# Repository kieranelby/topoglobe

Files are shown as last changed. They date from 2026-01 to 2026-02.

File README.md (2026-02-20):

# 3D Globe Segment Generator

Generate 3D-printable segments that assemble into a globe showing the Earth's ocean depth (Bathymetric) and land height (Topographic, or Raised-Relief).

## Overview

This python program combines elevation data and optional snow coverage data to create 3D models of Earth with raised relief features. The globe is divided into 48 segments that can be 3D printed and assembled. It was developed with the help of Claude Code.

## Appearance

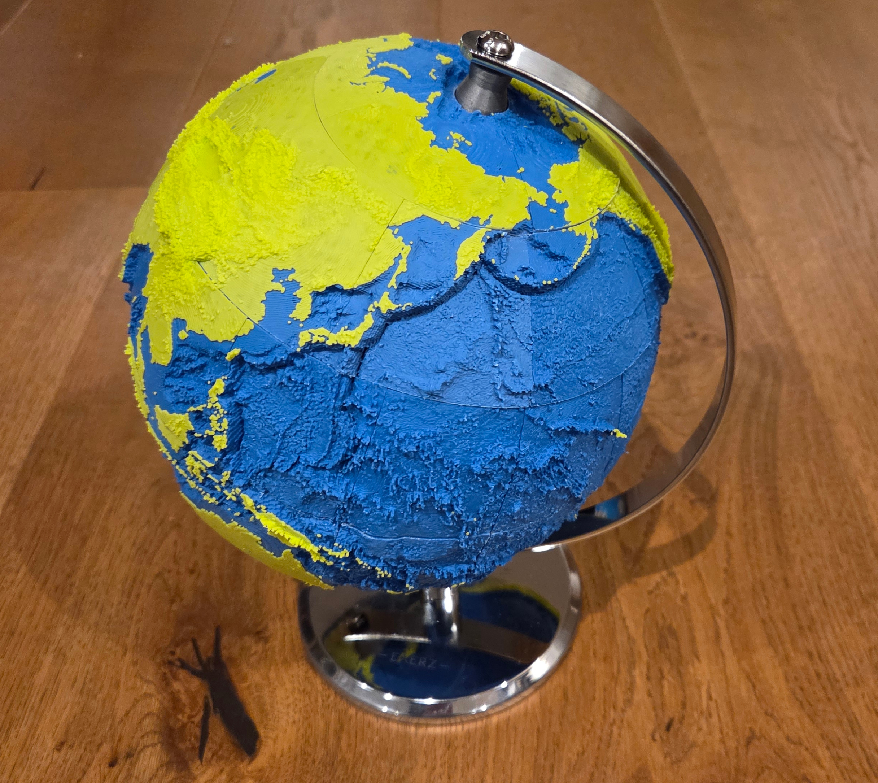
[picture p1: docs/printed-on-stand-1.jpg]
Photo of the printed globe on a stand showing sea off Japan.


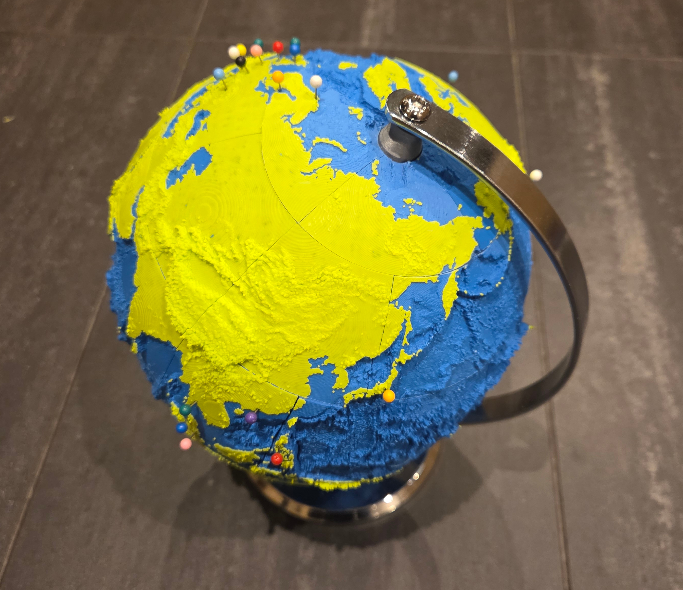
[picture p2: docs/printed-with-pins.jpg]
Photo of the printed globe on a stand with map pins.


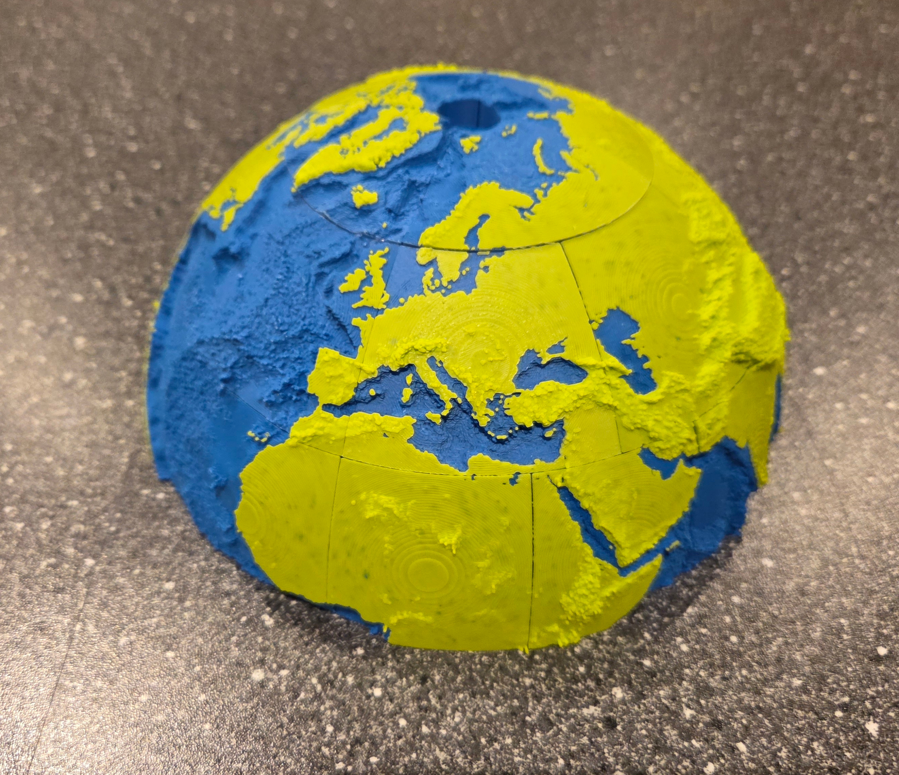
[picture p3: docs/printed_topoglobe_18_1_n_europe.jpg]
Photo of the printed Northern Hemisphere showing Europe.


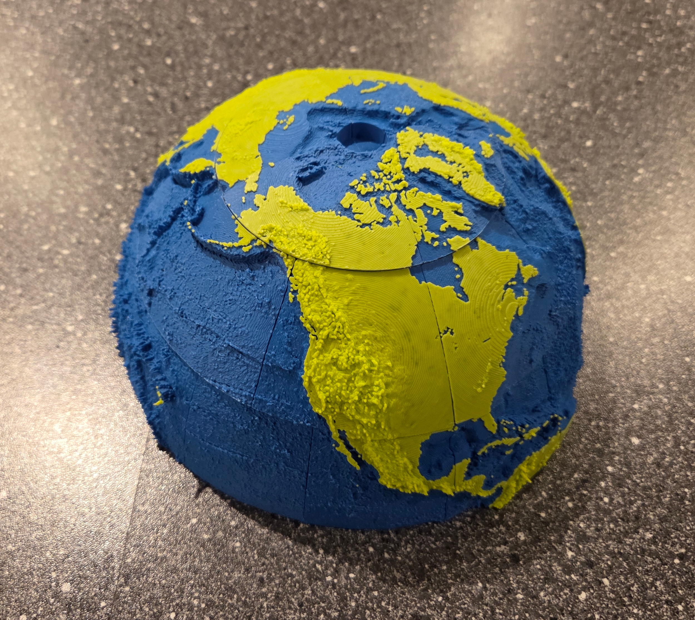
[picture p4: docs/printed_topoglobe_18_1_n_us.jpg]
Photo of the printed Northern Hemisphere showing the US.


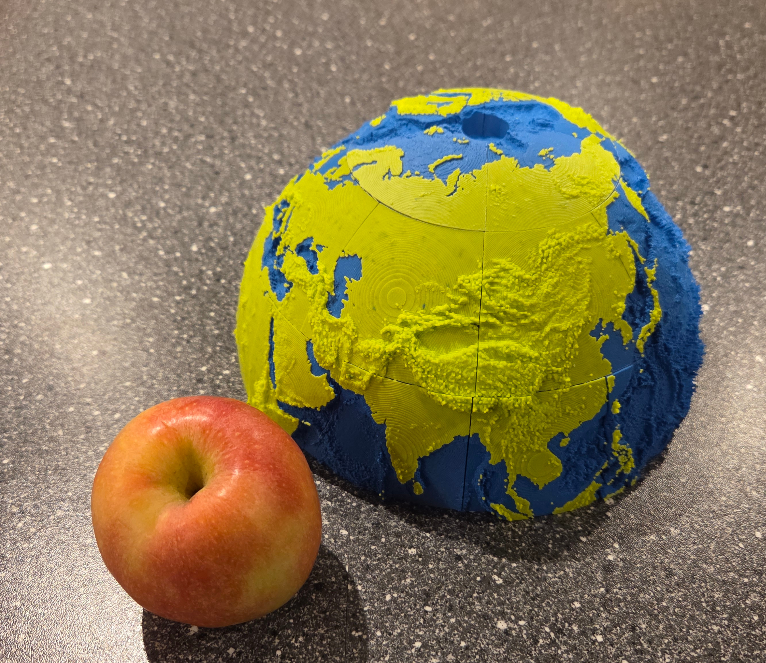
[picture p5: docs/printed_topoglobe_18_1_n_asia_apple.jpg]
Photo of the printed Northern Hemisphere showing Asia with an apple for scale.


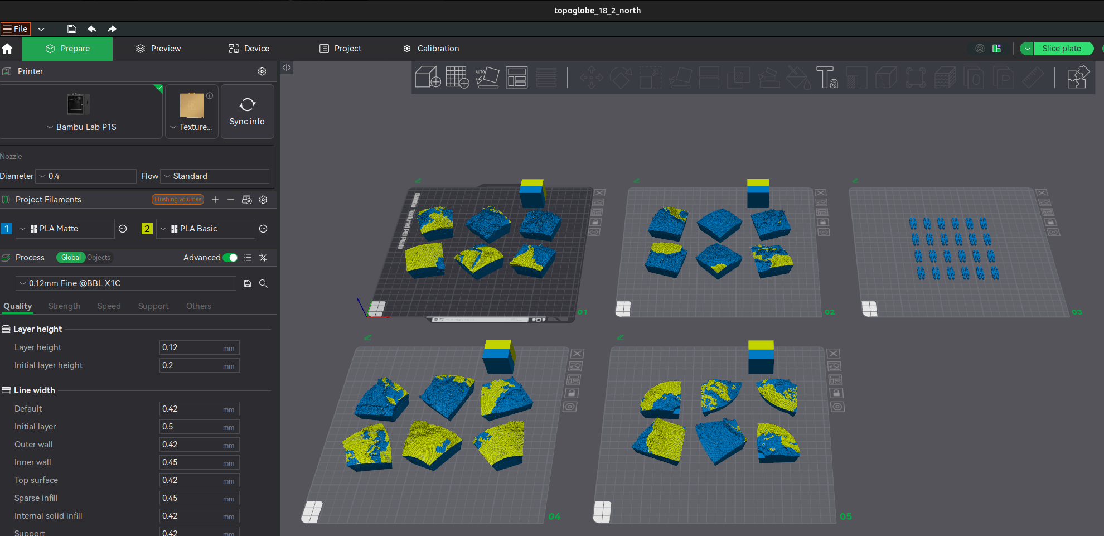
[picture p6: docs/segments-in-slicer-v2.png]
Screenshot of the Northern Hemisphere segments in a slicer.


## Print Ready 3D Files

The 3mf files are too big for github - they can be found on MakerWorld at:

 - [Northern Hemisphere 3mf on MakerWorld](https://makerworld.com/en/models/2254737-topoglobe-topographic-globe-kit-18cm-northern-half#profileId-2455952)
 - [Southern Hemisphere 3mf on MakerWorld](https://makerworld.com/en/models/2264577-topoglobe-topographic-globe-kit-18cm-southern-half#profileId-2467891)

The files are designed for Bambu Studio and have only been printed in a Bambu P1S so far.

## Installation

### Python Dependencies

Install required Python packages:
```bash
pip install -r requirements.txt
```

### Data Files

The geographic data is a bit large and may not be permitted under licensing rules to be included in this repo.

Instead, you will need to download the required data files and place them in the `data/` directory.

There are two data files. You may need to register (for free!) to get access.

#### ETOPO1 1 Arc-Minute Global Relief Model
- Version: ETOPO1 (deprecated!), Bedrock, Grid-Registered
- Download from: https://www.ncei.noaa.gov/products/etopo-global-relief-model
- Format: NetCDF (GMT .grd format)
- Resolution: 60 Arc Seconds
- Post-processing Needed: None
- Target filename: `./data/ETOPO1_Bed_g_gmt4.grd`

#### MODIS Snow Cover (Optional)
- Download from: https://nsidc.org/data/mod10cm
- Spatial Filter: Entire Globe
- Date: I used 1st June 2024 to approximate summer conditions. 
- Download Format: HDF
- Post-processing Needed: Yes
- Use TODO to convert HDF to GeoTIFF in EPSG:4326 projection
- Target filename: `./data/MOD10CM_snow_2024-153.tif`

## Configuration

Edit `config.yaml` if desired:

```yaml
# Data files
etopo_path: "./data/ETOPO1_Bed_g_gmt4.grd"
snow_path: "./data/MOD10CM_snow_2024-153.tif"  # Optional

# Globe parameters
radius_mm: 90.0              # Base radius in millimeters
elevation_range_mm: 15.0     # Height range for elevation features
min_height_mm: 0.2           # Minimum feature height
shell_thickness_mm: 7.0      # Wall thickness of the globe shell

# Grid parameters
step_deg: 0.333333           # Grid cell size in degrees (~37km at the equator)

# Output
output_dir: "./output"       # Directory for 3MF files
```

## Usage

### Generate All 48 Segments

```bash
python3 globe.py
```

This will generate all globe segments (without snow) and save them as 3MF files in the output directory. Takes approximately **9-10 minutes** for all 48 segments at 0.333333° resolution.

### Generate Specific Segments

```bash
python3 globe.py -s N60-90_E000-090 N60-90_E090-180
```

### Enable Snow Layer

```bash
python3 globe.py --snow
```

Snow is disabled by default for faster processing. Use `--snow` to include snow coverage data.

### Command Line Options

```
usage: globe.py [-h] [--config CONFIG] [--segments SEGMENTS [SEGMENTS ...]]
                [--output-dir OUTPUT_DIR] [--snow] [--verbose]

Generate 3D-printable globe segments from elevation data

optional arguments:
  -h, --help            show this help message and exit
  --config CONFIG, -c CONFIG
                        Path to configuration file (default: config.yaml)
  --segments SEGMENTS [SEGMENTS ...], -s SEGMENTS [SEGMENTS ...]
                        Generate specific segments (e.g., N60-90_E000-090)
  --output-dir OUTPUT_DIR, -o OUTPUT_DIR
                        Override output directory from config
  --snow                Enable snow layer (default: disabled)
  --verbose, -v         Enable verbose logging
```

## Segment Pattern

The globe is divided into 48 segments with increasing density towards the poles:

**Northern Hemisphere:**
- 4 segments: 60°-90° N (90° longitude each)
- 8 segments: 30°-60° N (45° longitude each)
- 12 segments: 0°-30° N (30° longitude each)

**Southern Hemisphere:**
- 12 segments: 0°-30° S (30° longitude each)
- 8 segments: 30°-60° S (45° longitude each)
- 4 segments: 60°-90° S (90° longitude each)

Segment naming: `{N|S}{lat_min}-{lat_max}_{E|W}{lon_min}-{lon_max}`

Examples:
- `N60-90_W180-090` - North Pole segment, 90-180° West
- `N60-90_E000-090` - North Pole segment, 0-90° East
- `S30-60_W090-045` - Southern mid-latitude, 45-90° West

## Output

Each segment is exported as a 3MF file containing **separate objects** for multi-color printing:

- **Water layer** - Ocean depths with hollow core (print in blue)
- **Land layer** - Terrain elevation (print in green/brown)
- **Snow layer** - Snow-covered areas (print in white, only if `--snow` enabled)

### Multi-Color Printing

The 3MF files contain each layer as a separate object, allowing you to assign different colors in your slicer:

1. Load the 3MF file in your slicer (PrusaSlicer, Cura, Bambu Studio, etc.)
2. You'll see 2-3 separate objects (water, land, and optionally snow)
3. Assign different colors/materials to each object
4. Slice and print!

### Segment Alignment

Cell boundaries are precisely aligned with segment edges, ensuring adjacent segments fit together perfectly when assembled.

## Architecture

```
globe.py                   # Main entry point - generates segment 3MFs
bambu_3mf.py               # Packages segments into Bambu Studio 3MFs
globe_generator/
├── config.py              # Configuration dataclasses
├── grid_builder.py        # Equal-area grid generation
├── data_processor.py      # Elevation and snow data processing
├── segment_generator.py   # 48-segment definition
├── mesh_generator.py      # Pure-Python mesh generation using trimesh
└── spherical_geometry.py  # Spherical coordinate and geometry utilities
snapfits/                  # Snap-fit connector pocket STL (from Connector1 Slim)
```

**Key Features:**
- **Pure-Python mesh generation**: Direct triangulation using `trimesh` - no external CAD software needed
- **Per-segment cell generation**: Cells are generated with boundaries aligned to segment edges for perfect assembly
- **Vectorized data processing**: 75x faster elevation sampling using NumPy/xarray vectorization
- **Multi-color 3MF export**: Separate objects for water, land, and snow layers
- **Adaptive subdivision**: Shell patches use ~1° per subdivision for smooth surfaces, small cell patches use efficient 4x4 grids

## Performance

**Processing Time (at 0.333333° resolution):**
- Per segment: ~10-12 seconds (pure-Python mesh generation)
- All 48 segments: ~9-10 minutes total
- Data processing: elevation sampling ~2 seconds, cell processing ~5 seconds per segment
- Mesh generation: ~3-5 seconds per segment

**Grid Resolution:**
- Cell size: 0.333333° (~37km at the equator, ~20 arc-minutes)
- Typical segment: 8,000-9,000 cells
- High detail capture of elevation features

**Memory Usage:**
- Python process uses ~500 MB RAM during mesh generation
- Data processing uses minimal memory (~200 MB)
- Total peak usage: < 1 GB

### 3MF File Size

Each segment 3MF file is typically **10-15 MB** at 0.333333° resolution, depending on terrain complexity.

**Total output size:** ~650 MB for all 48 segments

**Adjusting Grid Resolution:**

Edit `config.yaml` to adjust detail level:
- `step_deg: 0.333333` - High detail, ~37km cells (current)
- `step_deg: 0.5` - Medium detail, ~55km cells, faster generation
- `step_deg: 1.0` - Lower detail, ~110km cells, fastest generation

**Adjusting Shell Smoothness:**

Shell patches automatically use ~1° angular subdivision for professional-quality smooth surfaces. To adjust, edit `globe_generator/mesh_generator.py` line 196-197.

## Slicer

### Generating Bambu Studio 3MF Files

After generating the 48 segment 3MFs in `output/`, run `bambu_3mf.py` to produce Bambu Studio-ready files:

```bash
python3 bambu_3mf.py
```

This produces two files in `3mf/`:
- `topoglobe_18_2_north.3mf` - 24 northern hemisphere segments across 4 plates
- `topoglobe_18_2_south.3mf` - 24 southern hemisphere segments across 4 plates

Each file has filament colours pre-assigned (filament 1 = water, filament 2 = land) and segments arranged 6 per plate, so you can open them directly in Bambu Studio and slice.

Options:
```bash
python3 bambu_3mf.py --hemisphere north   # Only one hemisphere
python3 bambu_3mf.py --input-dir output --output-dir 3mf
```

### Print Settings

1. Open the generated 3MF in Bambu Studio.
2. Change the filaments so that filament 1 is the water colour and filament 2 is the land colour.
3. Choose the "0.12mm Fine" profile.

### Print-Ready Files on MakerWorld

The 3MF files are too big for GitHub. Pre-built print-ready files can be found on MakerWorld:

 - [Northern Hemisphere 3mf on MakerWorld](https://makerworld.com/en/models/2254737-topoglobe-topographic-globe-kit-18cm-northern-half#profileId-2455952)
 - [Southern Hemisphere 3mf on MakerWorld](https://makerworld.com/en/models/2264577-topoglobe-topographic-globe-kit-18cm-southern-half#profileId-2467891)

Screenshot of the Northern Hemisphere segments in a slicer.

## Assembly

Adjacent segments join together using snap-fit connectors based on [Connector1 Slim by DexTech on Printables](https://www.printables.com/model/1134923-connector1-slim). Each segment has snap-fit pockets cut into its east and west edges during mesh generation. A plate of matching connector pegs is included to print; snap them in to join segments side by side.

For the north-south joins between latitude bands, optionally use 80/120 grit sandpaper to roughen the edges slightly, then glue with SuperGlue.

Work up/down "ring-by-ring" from the equator, one hemisphere at a time.

## Decoration

The smallest sort of "map push pins" can be used to permanently mark locations (offices, places you've been, etc).

The trick is to heat up the pointy end just enough to plunge it into the globe, being careful to get it right first time - don't change direction.

Don't heat the pin up too much, or either the ball on the end of your pin will fall off, or you'll make a bigger hole than you wanted.  

Here's some specs from an [Example product on Amazon UK](https://www.amazon.co.uk/dp/B07XNQCWY5):

 - Material: plastic, stainless steel.
 - Ball head diameter: 0.13 in (3mm).
 - Needle length: 0.6 in (15mm).

## Stand

I found it easiest to "cannibalise" an existing off-the-shelf globe, and take its stand.

This globe was about the right size and had a very re-use friendly stand:

[Exerz 20cm World Globe Political Map at Amazon UK](https://www.amazon.co.uk/Exerz-20cm-World-Globe-Educational/dp/B08V144XH3)

There is an STL file included in this repo, `stand-attachment.stl`, generated from an OpenSCAD file, `stand-attachment.scad`, to make a suitable connector to join the globe to the stand:

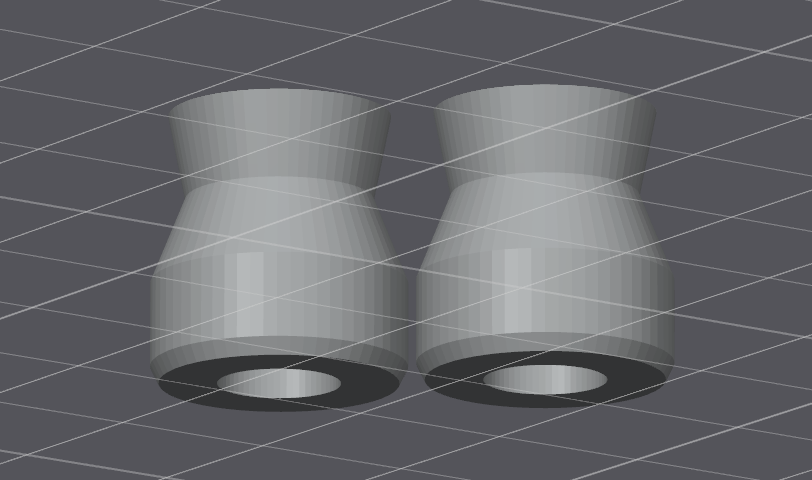
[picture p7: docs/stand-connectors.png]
Stand Connectors


## Testing

The project includes comprehensive test coverage with 32 tests.

### Quick Start

```bash
# Install dev dependencies
pip install -r requirements-dev.txt

# Run all tests
venv/bin/python3 -m pytest tests/ -v

# Run only fast unit tests (no data files required)
venv/bin/python3 -m pytest tests/ -v -m "not integration"
```

### Test Categories

**Unit Tests (24 tests)** - Fast, no data files required
- Configuration loading
- Grid generation algorithms
- Coordinate conversions
- Segment definitions

**Integration Tests (8 tests)** - Require ETOPO1/MODIS data files
- Full pipeline testing
- Data loading and processing
- Segment cell generation
- Cross-segment consistency

Integration tests automatically skip if data files are not present.

### Code Quality

```bash
# Run linters
./lint.sh

# Or individually
venv/bin/python3 -m ruff check .
venv/bin/python3 -m mypy globe_generator/*.py *.py
```

## Known Bugs

 - When in the default "no-snow" mode, some parts of Greenland are shown as water, but actually the land is below sea-level due to the weight of the ice! Sorry Greenland. I probably should have used the ice elevation not the bedrock elevation data set.
 - A few of the Northern Hemisphere segments have non-closed manifolds. They still seem to slice ok.
 - It could do with being quicker to print!
 - It would be nice to take a list of interesting co-ordinates (holiday locations? data-centres?) and have them turn into little crosses of a 3rd color.
 - The connectors only run east-west, you still have to glue the six "rings" together.
 - Possibly topoglobe could be slightly more aware of the physical limitation of 3d-printing; some very pointy volcanic islands are just too delicate, and some "stringing" occurs around rapid changes in sea-depth.

## License

This project is provided as-is for personal and educational use.

The 3mf files are provided under the Creative Commons Attribution—Noncommercial—Share Alike Licence - http://creativecommons.org/licenses/by-nc-sa/4.0/ .

The "snapfit" connectors used to hold the segments together are made by DexTech https://www.printables.com/@DexTech - see https://www.printables.com/model/1134923-connector1-slim and used under the same licence. Any blame for scaling the snapfits even smaller lies with me, not with DexTech!

On that note, please don't blame me if:
 - your 3D printer gives up or catches fire;
 - you get lost during your solo navigation around the world by coracle using only this globe for navigation;
 - your favourite island is missing.

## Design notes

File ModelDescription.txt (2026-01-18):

topoglobe Topographic Globe Kit 18cm Northern Half

This model, when assembled, is the top half (Northern Hemisphere) of a globe that shows the Earth's ocean depth (Bathymetric) and land height (Topographic, or Raised-Relief).

The diameter of the globe is approximately 180mm (18 cm, 7 inches). The height difference from deepest ocean to highest mountain is 15mm.

It uses two filament colours, one for land, and one for water.

It prints as 24 segments across four plates which require gluing together (e.g. with cyanoacrylate adhesive, aka SuperGlue). This reduces the number of colour changes required, since the land is mostly in the top layers.

To keep the size of the file small enough to upload, this model is just the Northern Hemisphere. The Southern Hemisphere can be found as a separate model (topoglobe Topographic Globe Kit 18cm Northern Half). They can be glued together to make the complete globe.

I printed this on a standard Bambu P1S using "0.12mm Fine" with Bambu PLA Matte (for water) and Bambu PLA Basic (for land) filament, with Support enabled (On build plate only, Type: normal(auto), Top interface layers: 1), using the same filament for water and for support.

Under those settings, it took about 1d 8h (32 hours) to print, using ~400g of filament for water/support and ~100g of filament for the land (including waste).

The model is based on the ETOPO Global Relief Model from NOAA. The resolution of the printed model is greatest at the equator, where each cell is 20 arc-minutes in size - about 37 kilometres, or 23 miles. Python code used to process the data can be found on github.com at kieranelby/topoglobe.

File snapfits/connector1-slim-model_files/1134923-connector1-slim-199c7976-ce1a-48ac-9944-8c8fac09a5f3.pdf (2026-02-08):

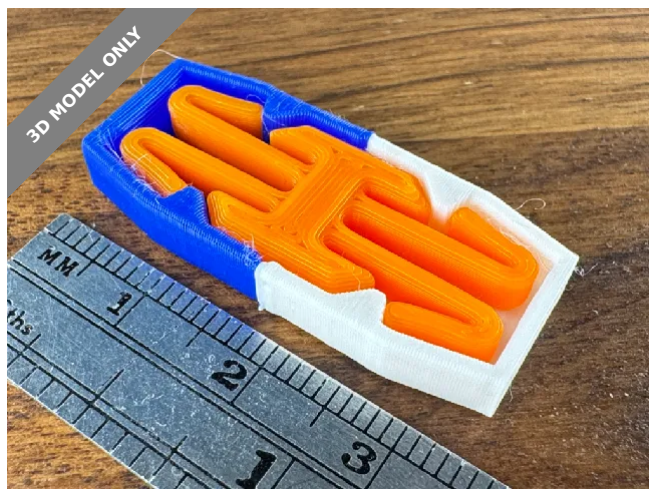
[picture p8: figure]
3D MODEL ONLY

## Summary

Clips to join two 3D printed parts without glue.

Hobby & Makers (https://printables.com/model?categoryId=48) > Mechanical Parts (https://printables.com/model?categoryId=51)

Clips to join two 3D printed parts without glue.

These clips index (locate) two parts together and hold them firmly together with a clamping force.

This is a slim version of the full size clips. These can be used in smaller or thinner models, where the full size clips will not fit.

The full size clips can be found here:

https://www.printables.com/model/1133096-connector1

Here is how they work:

How to use the files:

How to Use

Bring the model you want to have joined into PrusaSlicer.
Add as a negative volume modifier, Pocket 0 DOF.
Ensure that the negative volume modifier is at the Z height where you want to split your model.

DexTech (https://printables.com/@DexTech_87923)

## Connector1, Slim

VIEW IN BROWSER (https://printables.com/model/1134923-connector1-slim)

updated 12. 1. 2025 | published 12. 1. 2025

1.
2.
3.

If your print will need more than one connector, add an additional negative volume modifier. Consider using Pocket 1 DOF, which has additional clearance on one side of the pocket, so as to not over-constrain the connectors. Be sure to align this pocket with the first one.
Use the PrusaSlicer Cut command to split your model a the desired Z height - this should be the same as your Pocket negative volume modifiers. Orient both resultant parts on their cut face.

Settings: 0.4 mm nozzle, 0.2 mm layer height

Tested with PLA and PETG, but other similar plastics will likely work as well.

Files

Clip, Slim (0.0 Clearance).stl
Clip, Slim (0.1 Clearance).stl

Only one of these is needed. I recommend starting with the 0.0 clearance version. If the fit feels too tight, try the 0.1 clearance version.

Clip Stud, Slim (0.0 Clearance).stl
Clip Stud, Slim (0.1 Clearance).stl

Use Clip Stud to temporarily join parts for fit checks if desired. Only one of these is needed. I recommend starting with the 0.0 clearance version. If the fit feels too tight, try the 0.1 clearance version.

Pocket 0 DOF, Slim.stl
Pocket 1 DOF, Slim.stl

The Pocket models are used as negative volume modifiers to create the cut-out for the connector clips. Use Pocket 0 DOF first. If additional connectors are required, consider using Pocket 1 DOF for the second one, which has additional clearance on one side of the pocket, so as to not over-constrain the connectors.

Min Size Part.stl

To use as a reference model for your designs. This model represents the volume required for the clip plus a minimum surrounding wall thickness.

Demo Part X, Slim.stl

These are demo and testing parts for the connector.

Connector1.f3d

4.

5.

## Model files

Editable Fusion 360 file to remix your own versions. For the “Slim” version, set the "PocketHeight" parameter to 4mm.

- Demo Parts | 5 files

demo-part-2-slim-r1.stl

demo-part-1-slim-r1.stl

demo-part-5-slim-r1.stl

demo-part-3-slim-r1.stl

demo-part-4-slim-r1.stl

clip-slim-00-clearance-r2.stl

clip-slim-01-clearance-r2.stl

## License

This work is licensed under a
Creative Commons (4.0 International License)

Attribution—Noncommercial—Share Alike (http://creativecommons.org/licenses/by-nc-sa/4.0/)

✖ | Sharing without ATTRIBUTION
✔ | Remix Culture allowed
✖ | Commercial Use
✖ | Free Cultural Works
✖ | Meets Open Definition

clip-stud-slim-00-clearance-r2.stl

clip-stud-slim-01-clearance-r2.stl

pocket-0-dof-slim-r1.stl

pocket-1-dof-slim-r1.stl

connector1-r1.f3d

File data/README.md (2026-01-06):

# Data Directory

This directory contains the geospatial data files used to generate the globe segments.

## Required Files

### ETOPO1 Global Relief Model (Required)
- **Filename**: `ETOPO1_Bed_g_gmt4.grd`
- **Size**: ~891 MB
- **Format**: NetCDF (GMT .grd format)
- **Resolution**: 1 arc-minute
- **Download**: https://www.ncei.noaa.gov/products/etopo-global-relief-model
- **Description**: Global elevation data including ocean bathymetry and land topography

### MODIS Snow Cover (Optional)
- **Filename**: `MOD10CM_snow_2024-153.tif` (or similar)
- **Size**: ~25 MB
- **Format**: GeoTIFF in EPSG:4326 projection
- **Download**: https://nsidc.org/data/mod10cm
- **Description**: Monthly snow cover percentage data
- **Note**: Only needed if generating globe segments with snow layer (`--snow` flag)

## File Locations

After downloading, the data files should be placed in this directory:
```
data/
├── ETOPO1_Bed_g_gmt4.grd
└── MOD10CM_snow_2024-153.tif
```

Then update `config.yaml` to point to these files:
```yaml
etopo_path: "./data/ETOPO1_Bed_g_gmt4.grd"
snow_path: "./data/MOD10CM_snow_2024-153.tif"
```

## Note

These files are not included in the repository due to their large size. You must download them separately from the sources listed above.

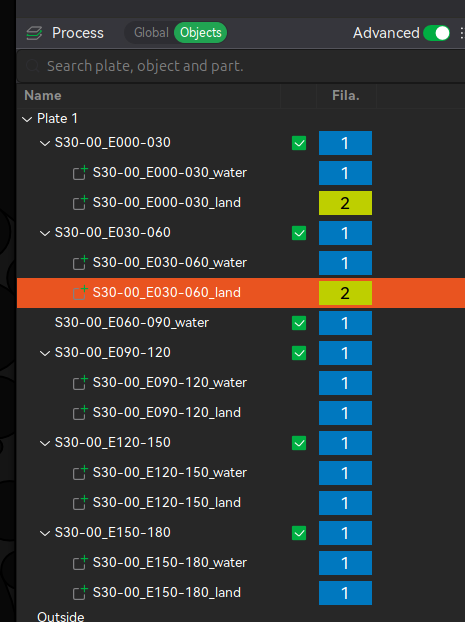
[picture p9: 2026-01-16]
docs/slicer-choosing-land-part-filament.png

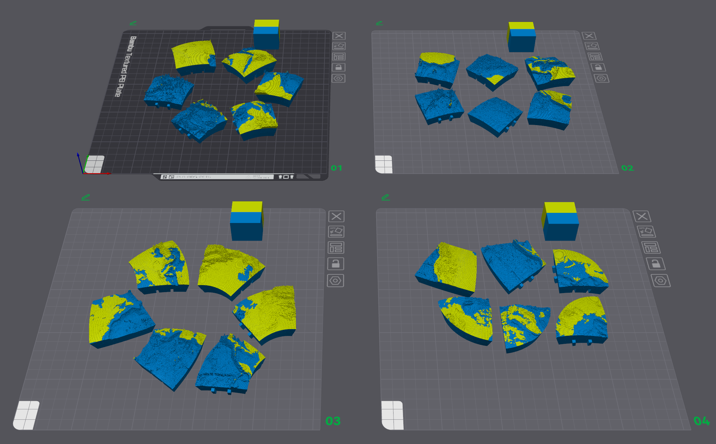
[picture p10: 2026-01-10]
docs/segments-in-slicer.png

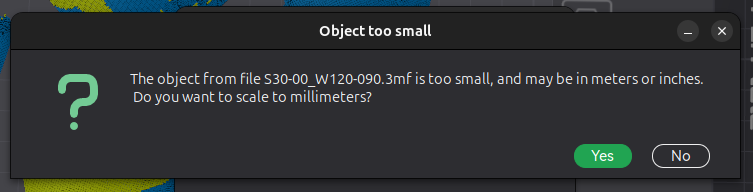
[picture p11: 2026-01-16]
docs/slicer-no-scale.png

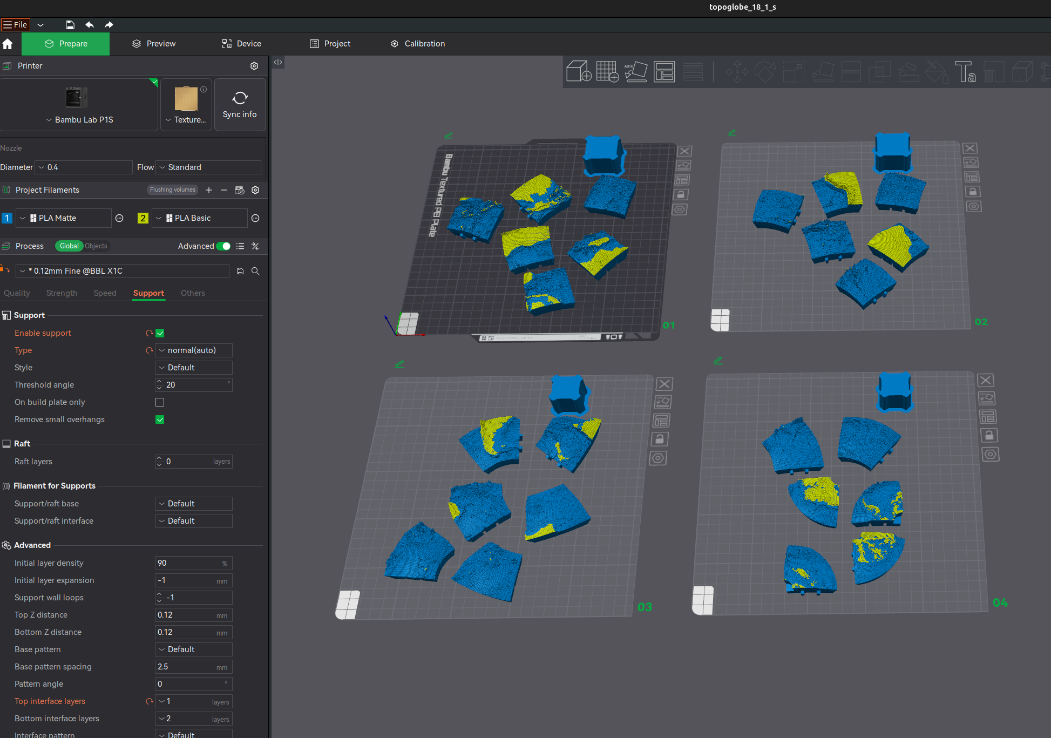
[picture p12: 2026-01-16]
docs/segments-in-slicer-southern.png

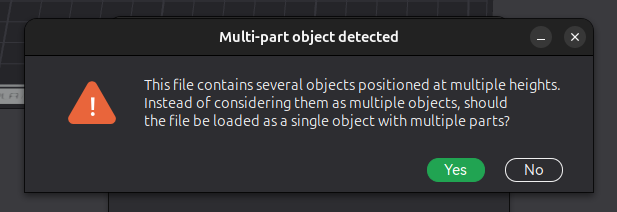
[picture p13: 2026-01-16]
docs/slicer-several-objects-as-one.png

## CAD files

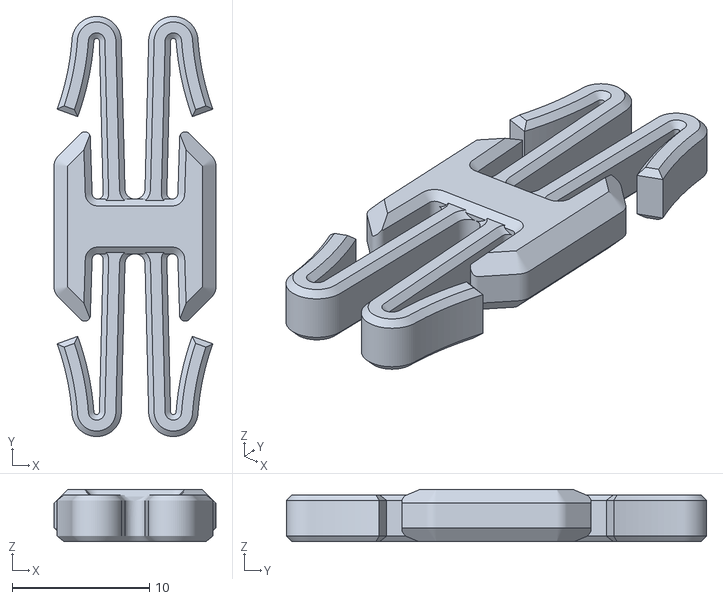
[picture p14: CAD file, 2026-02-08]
snapfits/connector1-slim-model_files/clip-slim-01-clearance-r2.stl
11.8 x 30.6 x 3.80

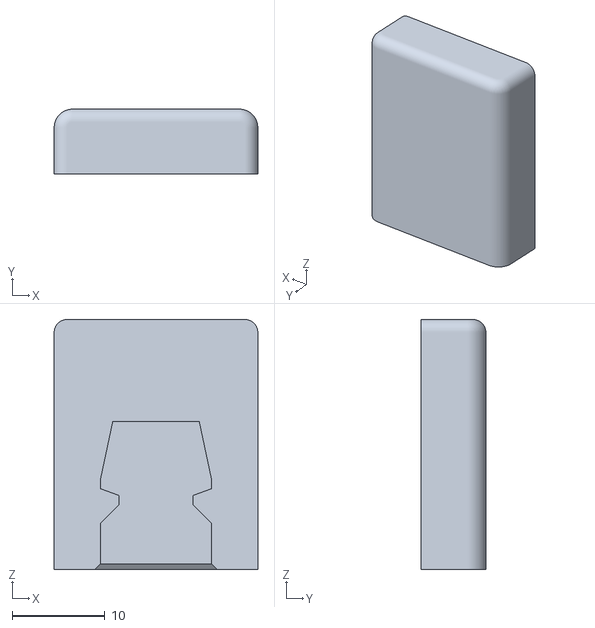
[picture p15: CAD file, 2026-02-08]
snapfits/connector1-slim-model_files/Demo Parts/demo-part-5-slim-r1.stl
22.0 x 7.00 x 27.0

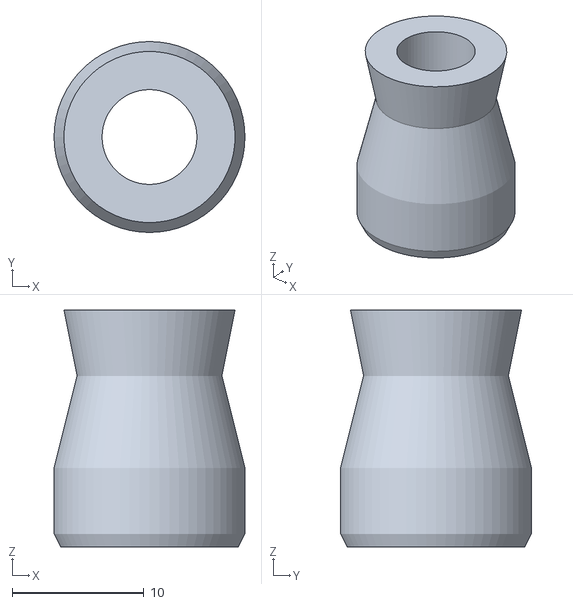
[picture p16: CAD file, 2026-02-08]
stand-atttachment.stl
14.5 x 14.5 x 18.0

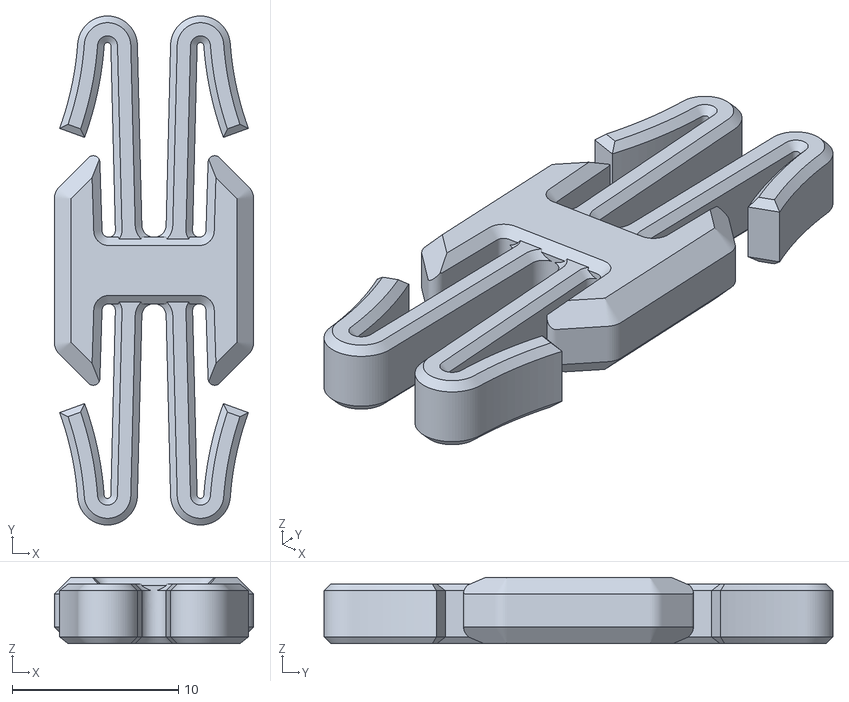
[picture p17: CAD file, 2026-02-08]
snapfits/connector1-slim-model_files/clip-slim-00-clearance-r2.stl
12.0 x 30.6 x 3.98

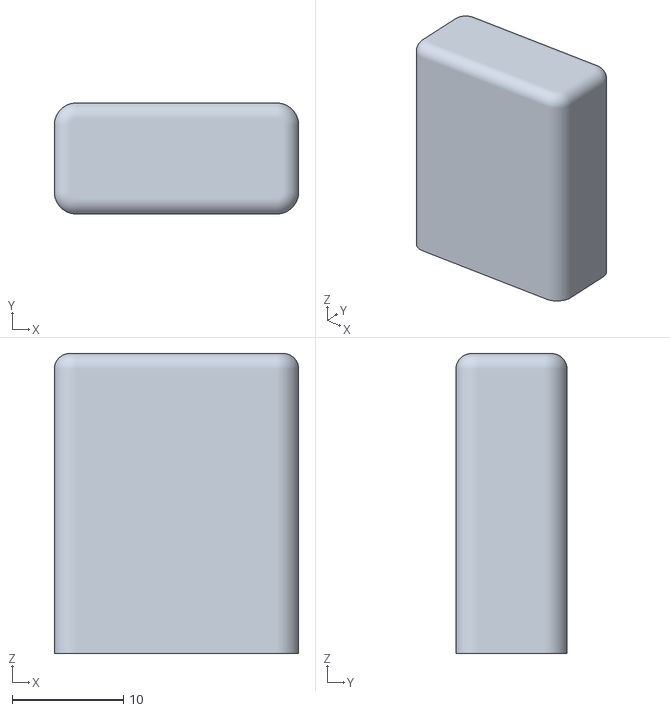
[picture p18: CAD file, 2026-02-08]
snapfits/connector1-slim-model_files/Demo Parts/demo-part-4-slim-r1.stl
22.0 x 10.0 x 27.0

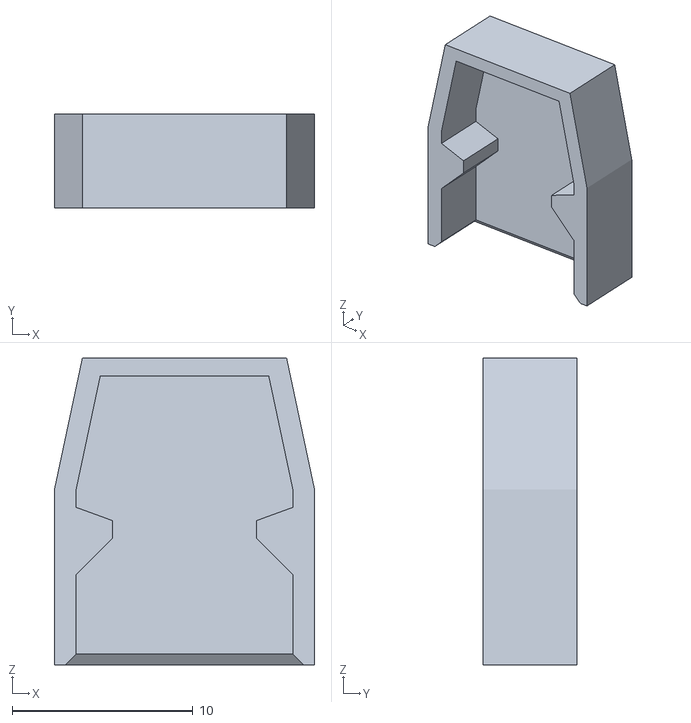
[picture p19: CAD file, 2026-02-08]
snapfits/connector1-slim-model_files/Demo Parts/demo-part-2-slim-r1.stl
14.4 x 5.20 x 17.0

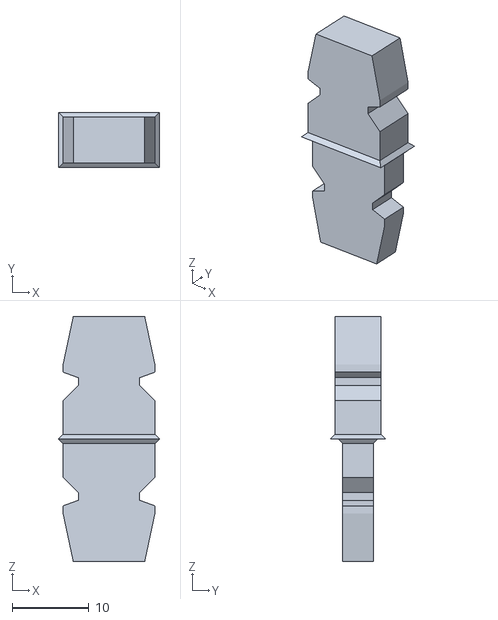
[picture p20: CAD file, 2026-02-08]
snapfits/connector1-slim-model_files/pocket-1-dof-slim-r1.stl
13.2 x 7.20 x 32.0

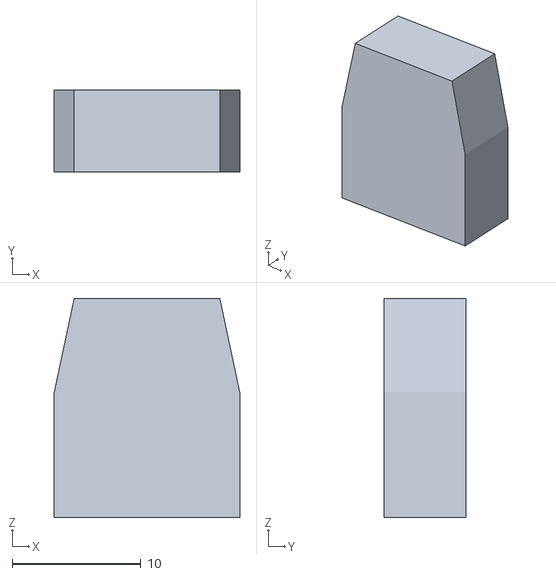
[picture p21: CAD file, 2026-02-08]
snapfits/connector1-slim-model_files/Demo Parts/demo-part-1-slim-r1.stl
14.4 x 6.40 x 17.0

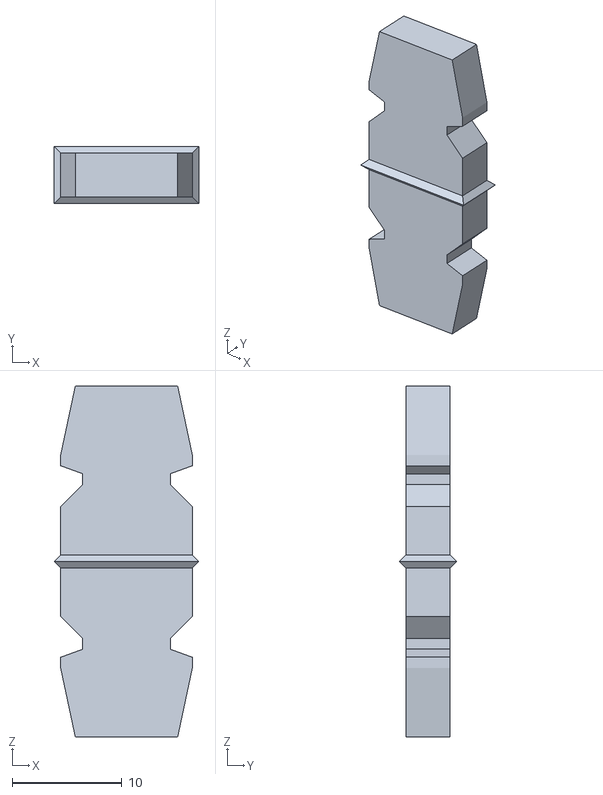
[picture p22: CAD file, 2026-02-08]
snapfits/connector1-slim-model_files/pocket-0-dof-slim-r1.stl
13.2 x 5.20 x 32.0

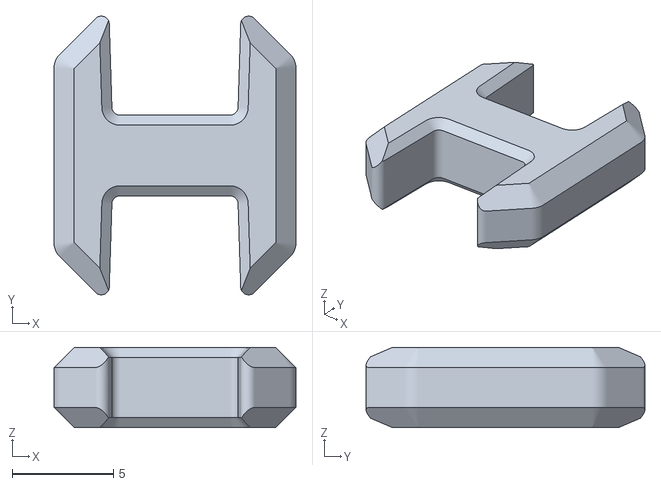
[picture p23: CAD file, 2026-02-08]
snapfits/connector1-slim-model_files/clip-stud-slim-00-clearance-r2.stl
12.0 x 13.8 x 3.98

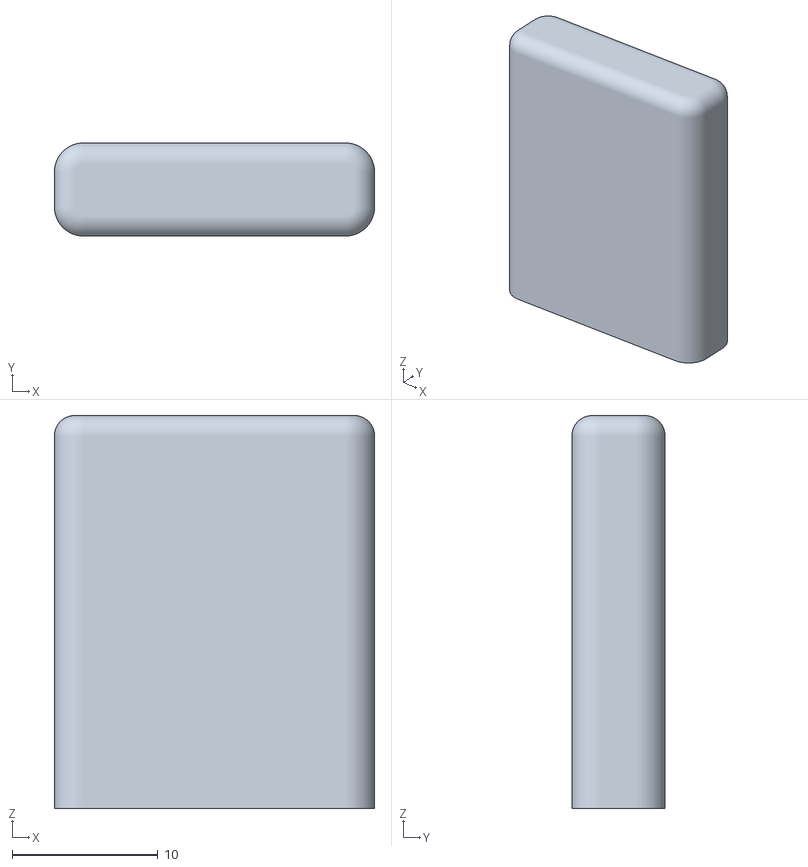
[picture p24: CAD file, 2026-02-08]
snapfits/connector1-slim-model_files/Demo Parts/demo-part-3-slim-r1.stl
22.0 x 6.40 x 27.0

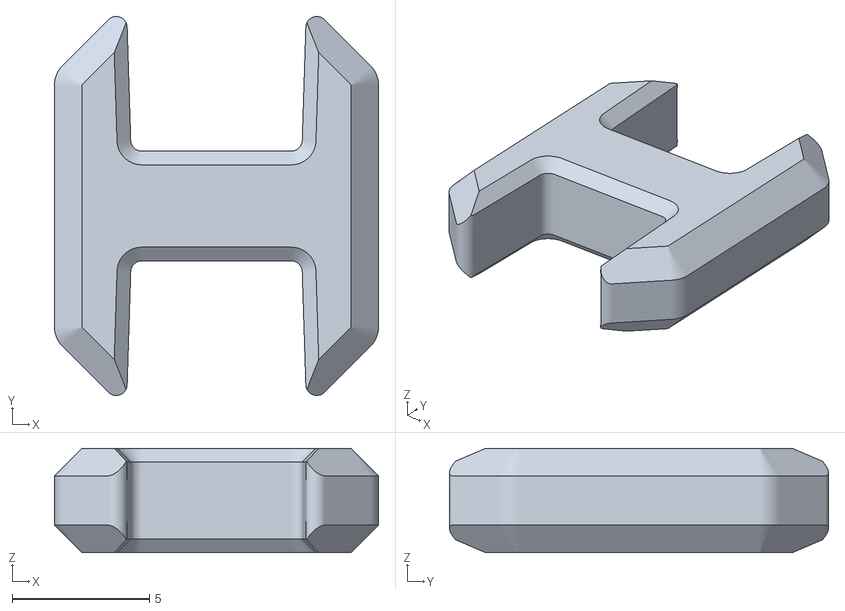
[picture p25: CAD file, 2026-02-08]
snapfits/connector1-slim-model_files/clip-stud-slim-01-clearance-r2.stl
11.8 x 13.8 x 3.80

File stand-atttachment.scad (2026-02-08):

$fn = 60;
height = 18;
th = 5;
bbh = 1;
bh = 5;
mh = height - th - bh - bbh;
hr = 3.6;
bbr = 6.75;
br = 7.25;
mr = 5.5;
tr = 6.5;
eps = 0.01;
difference() {
    union() {
        translate([0,0,bbh/2]) {
            cylinder(h = bbh, r1 = bbr, r2 = br, center = true);
        }
        translate([0,0,bbh + bh/2]) {
            cylinder(h = bh, r = br, center = true);
        }
        translate([0,0,bbh + bh + mh/2]) {
            cylinder(h = mh, r1 = br, r2 = mr, center = true);
        }
        translate([0,0,bbh + bh + mh + th/2]) {
            cylinder(h = th, r1 = mr, r2 = tr, center = true);
        }
    }
    translate([0, 0, height/2]) {
        cylinder(h = height + 2*eps, r = hr, center = true);
    }
}

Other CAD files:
3mf/settings.3mf
snapfits/connector1-slim-model_files/connector1-r1.f3d

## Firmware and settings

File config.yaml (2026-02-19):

# Data files
etopo_path: "./data/ETOPO1_Bed_g_gmt4.grd"
snow_path: "./data/MOD10CM_snow_2024-153.tif"

# Globe parameters
radius_mm: 90.0
elevation_range_mm: 15.0
min_height_mm: 0.5
shell_thickness_mm: 7.5

# Grid parameters
step_deg: 0.333333

# Pole holes for mounting stand (degrees from pole, approximate due to cell boundaries)
pole_hole_approx_radius_deg: 5.0

# Output
output_dir: "./output"

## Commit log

2026-01-03 Replace hollow_radius_mm with shell_thickness_mm config parameter
    Instead of specifying the absolute hollow core radius, users now specify
    the desired shell thickness. The hollow_radius_mm is calculated dynamically
    as: core_radius_mm - shell_thickness_mm. This makes configuration more
    intuitive since shell thickness is independent of elevation data.
    [config.yaml]
2026-01-03 Add tab and cutout system for easier globe assembly
    Implements interlocking tabs and cutouts on segment edges to facilitate
    assembly of the 48-segment globe.
    Features:
    - Tabs on eastern edge of each segment (3° x 3°, half shell thickness)
    - Cutouts on western edge with 0.2mm clearance for fit tolerance
    - Split shell architecture (outer + inner layers) to create cutouts
    without boolean subtraction operations
    - Configurable tab size (tab_size_degrees) and clearance (clearance_mm)
    The tab extends from hollow_radius_mm outward by shell_thickness_mm/2.
    The cutout is slightly larger than the tab (clearance on all sides) to
    ensure segments can be assembled without interference.
    🤖 Generate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
    [config.yaml]
2026-01-03 Fix rotation issue for segments with single sphere patch
    Segments with only one sphere patch (e.g., S30-00_W120-090) had incorrect
    rotation because unfused shapes retained individual Placements from
    make_sphere_patch, which interfered with the global rotation applied later.
    Solution: Fuse single shapes with a copy of themselves to ensure consistent
    behavior with multi-patch segments. This approach avoids the RAM issues
    that occurred when applying rotation as geometric transformation.
2026-01-03 Update documentation to reflect subprocess-based FreeCAD usage
    Since FreeCAD is now used as a subprocess (freecad --console) rather than
    imported as a Python library, the installation requirements are simplified:
    - Snap version now works and is recommended as easiest installation
    - No longer need python3-freecad package
    - No need to verify Python module import
    - Any FreeCAD installation method works (snap, apt, PPA)
    Updated both README.md and CLAUDE.md to reflect current architecture.
2026-01-03 Implement dual tab/cutout system for improved segment assembly
    Changed from single tab/cutout to dual tabs/cutouts positioned at 1/3
    and 2/3 of segment height for better interlocking.
    Key changes:
    - Dual cutouts on western edge at 1/3 and 2/3 height
    - Inner shell split into 5 patches (south, center, north, east-lower, east-upper)
    - Dual tabs on eastern edge matching cutout positions
    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
2026-01-03 Simplify shell structure to use full-thickness patches
    Changed from split inner/outer shell approach to single full-thickness
    patches. Since cutouts need to accommodate full-thickness (10mm) tabs,
    there's no need to maintain separate 5mm inner and 5mm outer layers.
    Changes:
    - Create 5 shell patches directly with full shell_thickness_mm (10mm)
    - Removed unnecessary inner/outer layer split
    - Reduced from 10 half-thickness patches to 5 full-thickness patches
    - Simpler code and fewer shapes to fuse (better performance)
    Cutouts now properly match tab thickness for correct assembly.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
2026-01-03 Apply clearance radially by reducing tab thickness
    - Tabs now have reduced thickness (shell_thickness - clearance) instead of full shell thickness
    - Cutouts remain at full shell thickness with same angular size as tabs
    - This provides radial clearance instead of angular clearance for easier assembly
    - Also add segment ID prefix to object names in 3MF files for better identification in slicers
2026-01-06 Add linting infrastructure with ruff and mypy
    Set up comprehensive code quality tooling:
    - Added ruff for fast linting (style, imports, code quality)
    - Added mypy for static type checking
    - Created lint.sh script for convenient checking
    - Auto-fixed 52 code quality issues:
    - Organized imports with isort
    - Removed unused imports
    - Modernized type annotations (Optional[X] → X | None, List → list, etc.)
    - Simplified code patterns (ternary operators, f-strings)
    - Removed unnecessary code
    Configuration in pyproject.toml with pragmatic settings for data science libraries.
    Both linters now pass cleanly on entire codebase.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
2026-01-06 Convert integration tests to pytest format
    Converted test_data_processing.py to proper pytest integration tests:
    - Created tests/test_integration.py with 8 integration tests
    - Added pytest markers for integration tests (@pytest.mark.integration)
    - Tests gracefully skip if data files are not available
    - Converted test_data_processing.py to friendly wrapper script
    Integration test coverage:
    - Dataset loading (ETOPO1, MODIS)
    - Global elevation range computation
    - Segment cell processing and boundary alignment
    - Snow data processing
    - Cross-segment consistency
    Benefits:
    - Consistent testing framework across all tests
    - Can run separately: pytest -m integration
    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
2026-01-06 Remove all FreeCAD references - project now uses trimesh
    Removed all references to FreeCAD throughout the codebase:
    - Deleted globe_generator/exporter.py (legacy FreeCAD exporter, unused)
    - Updated CLAUDE.md to remove FreeCAD installation and architecture references
    - Updated README.md to remove FreeCAD comparison section
    - Updated code comments in globe.py and mesh_generator.py
    - Simplified setup instructions (no external dependencies)
    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
2026-01-11 Add pole hole feature for mounting stand
    Adds optional pole_hole_approx_radius_deg config option that creates
    flat shell areas at the poles (no elevation relief) for mounting the
    globe on a stand. Cells within the specified radius of either pole
    have their water/land/snow heights set to zero.
2026-01-16 add printed images
2026-01-18 update docs
    [stand-atttachment.scad, stand-atttachment.stl]
2026-02-08 Add flat inner surface to globe segments for support-free printing
    Shell and tab patches now have flat inner surfaces instead of curved
    spherical ones. The flat plane is computed in the rotated print
    orientation, maintaining minimum wall thickness at segment center
    while increasing thickness toward edges.
2026-02-08 tweak stand attachment size
    [stand-atttachment.scad, stand-atttachment.stl]
2026-02-08 Remove tabs/slots and simplify shell to flat quadrilateral base
    - Remove tab_size_degrees and clearance_mm config parameters
    - Remove create_tab_patches() and simplify create_shell_patches() to
    create_shell_patch() generating a single flush shell
    - Flat inner surface is now a proper quadrilateral: 4 corners projected
    to the flat plane with bilinear interpolation for interior vertices
    - Side walls connect curved outer edge straight down to flat quad edges
    - Calculate flat_z from minimum Z of segment corners for proper base
    This eliminates the fiddly tab/slot assembly system and creates
    segments with flush edges and flat bases for support-free printing.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
    [config.yaml]
2026-02-08 Add snap-fit pockets on east/west segment edges
    Uses connector1-slim pocket design from Printables. Half-pocket (16mm)
    is subtracted from shell at edge midpoints via boolean difference.
    Pockets are oriented with opening facing outward from segment.
    [clip-slim-00-clearance-r2.stl, clip-slim-01-clearance-r2.stl, clip-stud-slim-00-clearance-r2.stl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]
2026-02-19 Add automated Bambu Studio 3MF generation
    Add bambu_3mf.py to package trimesh segment 3MFs into Bambu Studio-compatible
    hemisphere files with pre-assigned extruder colours, plate layouts, and slicer
    settings from a template (3mf/settings.3mf). This replaces the previous manual
    import workflow in Bambu Studio.
    Update README with snap-fit connector assembly instructions (Connector1 Slim)
    and the new automated slicer workflow.
2026-02-19 Add snap-fit clip plate and update licensing in README
    Add a 5th plate to each hemisphere 3MF containing 24 snap-fit connector
    clips (clip-slim-00-clearance-r2.stl) scaled to 75%, arranged in a 6x4
    grid centered on the build plate.
    Also update README with CC BY-NC-SA 4.0 licence, DexTech attribution
    for snap-fit connectors, and revised known bugs.
2026-02-19 Fix clip plate position to right of segment grid
    Position the clip plate at column 2, row 0 so Bambu Studio shows
    S S C / S S instead of S S / S S / C.
2026-02-19 Track slicer settings template in git
    Allow 3mf/settings.3mf through .gitignore so the Bambu Studio settings
    template is version-controlled while other .3mf files remain ignored.
    [settings.3mf]
